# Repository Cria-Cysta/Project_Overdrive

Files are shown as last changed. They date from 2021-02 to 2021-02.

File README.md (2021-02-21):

# Project overdrive

Overdrive Model Ver. 21B20

>中文版介绍请点击[这里](https://shimo.im/docs/xqpTWwy3x8qtTTDj/)。

### What is it?

It's a game controller which designed for SDVX E-cloud, USC, KSM.

Compared with other controllers, it has a compromise size. When I designing this controller, I have tried to find a size to adapt to as many hand shapes as possible. And that it is.

### Features

It have bigger size to allow you could easily touch the BT-button. 3D-printed BT-buttons make the   finger contact area larger than standard keyboard key. Slightly inward moved position of FX-button relaxed your thumbs when you're playing.

### Materials

In order to make this controller, you'll need: 

1. Cover 3D-printed parts ×1
2. Middle bracket 3D-printed parts ×1
3. Lower lid 3D-printed parts ×1
4. BT-button 3D-printed parts ×4
5. EC11 rotary encoder ×2
6. PCB ×1 (thickness: 1.6mm)
7. Keyboard axis ×7
8. Satellite axis ×8
9. Pro micro development board ×1, With solder pins
10. Several GB M2×18 countersunk screw 
11. 20cm Micro USB male to female Type-C converter ×1.
12. Φ25mm knob ×2
13. 1u×1u DSA Keycap ×1
14. 1u×1.75u DSA Keycap ×2
15. Φ10mm mat ×4

In addition, you also need to prepare solder, flux, electric soldering iron and other tools used to solder the circuit board, as well as a small Phillips screwdriver. Because 3D-printed parts may have dimensional tolerances, prepare sandpaper as appropriate. 

### Guide

In production, stay tuned ;-)

Because it is designed to be easy to assemble, you can try to assemble it yourself.

### About design

Q: Why is the appearance very round, despite the use of 3D printing, there is no design of extra protrusions?
A: When playing SDVX E-cloud or other laser-shoot-type games, due to the variety of gameplay requirements, if you are not familiar with the chart or playing the difficult music chart, it may lead to violent operations that vary from person to person. The smooth appearance can maximize the protection of the user's hands when playing.

Q: Why are there chamfers near the buttons?
A: Since this controller is a miniaturized controller, the size standard part refers to a part that made for a mechanical keyboard. The specifications of the BT button 2U*2U are not guaranteed to fit everyone's hands. Therefore, in order to prevent the nails from reaching the gap and being caught, all buttons are designed with chamfers. 

Q: Why did the position of the FX button move inward?
A: The two FX buttons move inward for convenience. The design of the controller is for ease of use or to restore the feel of the arcade. These two design directions will inevitably have contradictions in some aspects. The inward movement of the FX button can reduce the accumulation of fatigue caused by long-term play under the design of the hand console, and it can also take care of players with relatively short finger lengths.

Q: Why is there no LED light like other miniaturized controllers?
A: Future versions consider adding this feature.

Q: Since the design is based on the size of the mechanical keyboard, why does the controller use non-standard BT keys?
A: The shaft of the existing 2U*2U keys on the market is not in the center. Whether it is adding a shaft body or filling the remaining slots with a satellite shaft, it will seriously affect the feel of the button and the force feedback. 

### Others

This work is licensed under a Creative Commons Attribution-NonCommercial-ShareAlike 4.0 International License.

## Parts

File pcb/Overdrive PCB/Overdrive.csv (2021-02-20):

ID | 位号 | 包 | 数量 | 名称 | 供应商和位号
1 | U1 | SparkfunPromicro | 1 | ProMicro
2 | START1 | MXOnly-1U-NoLED | 1 | KEYSW
3 | FX-R1,FX-L1 | MXOnly-1.75U-NoLED | 2 | KEYSW
4 | BT-D1,BT-C1,BT-B1,BT-A1 | MXOnly-2U-NoLED | 4 | KEYSW
5 | LASER-R1,LASER-L1 | RotaryEncoder_Alps_EC11E_Vertical_H20mm | 2 | EC11_without_switch

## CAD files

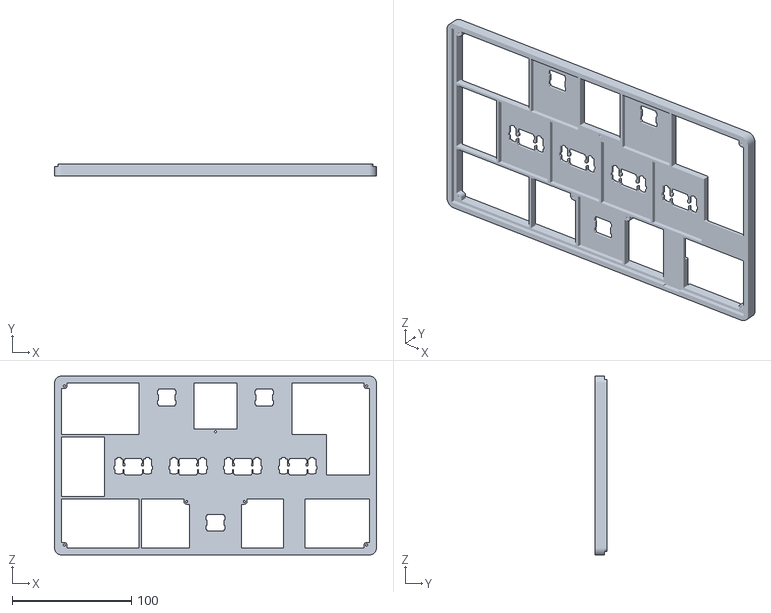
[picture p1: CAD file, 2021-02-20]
model/Middle_bracket.STL
270.0 x 10.0 x 150.0

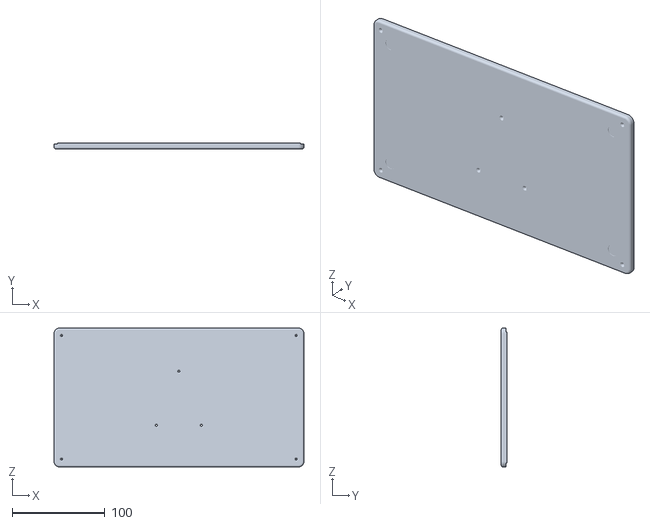
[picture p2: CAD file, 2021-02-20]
model/Lower_lid.STL
270.0 x 6.20 x 150.0

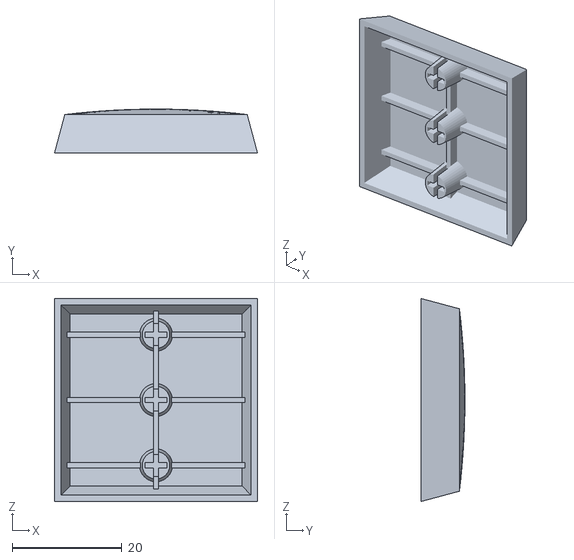
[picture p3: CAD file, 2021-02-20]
model/BT.STL
37.0 x 8.00 x 37.0

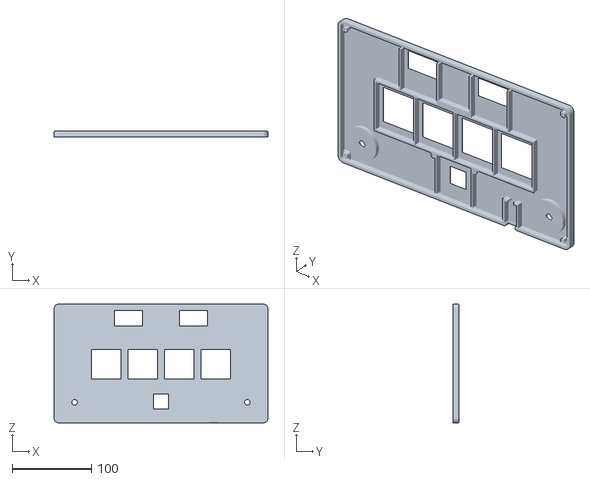
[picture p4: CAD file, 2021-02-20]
model/Cover.STL
270.0 x 8.00 x 150.0

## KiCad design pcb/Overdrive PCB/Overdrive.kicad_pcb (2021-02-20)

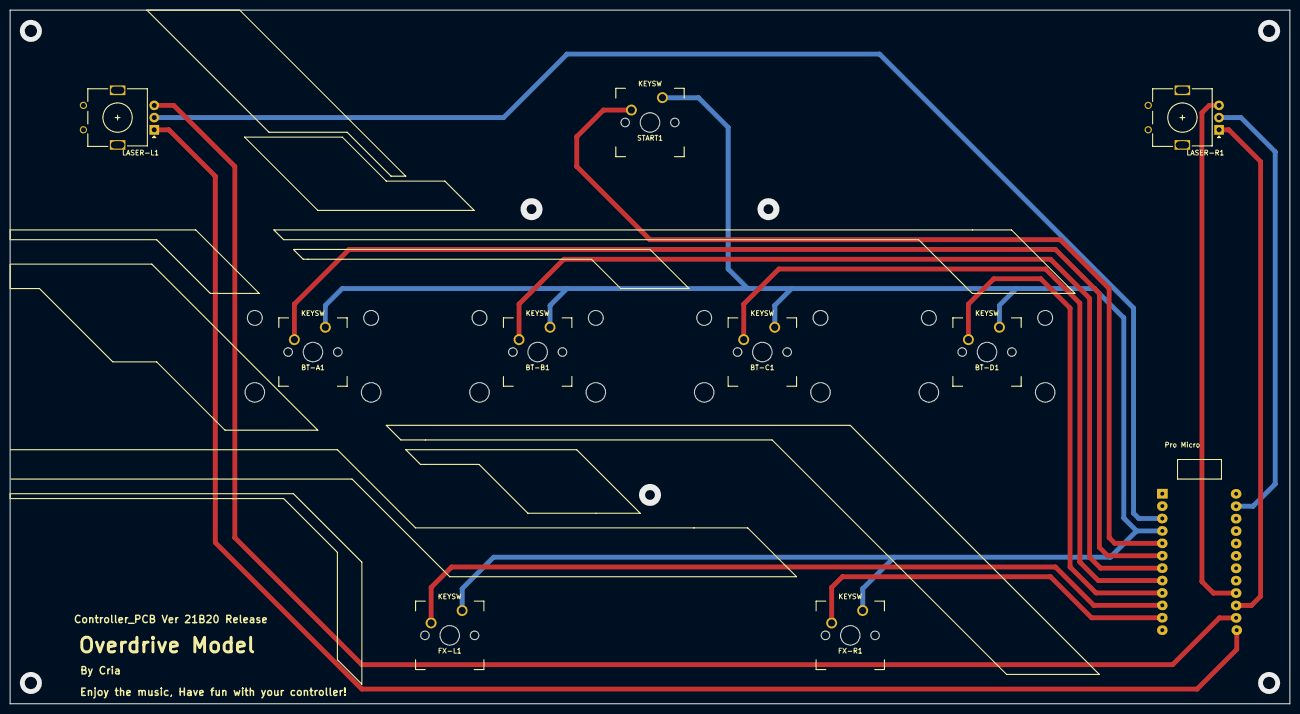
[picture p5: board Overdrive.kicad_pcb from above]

Board: 2 copper layers, 262.0 x 142.0 mm, 10 parts (0 on the bottom side), 14 nets.

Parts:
BT-A1: KEYSW; MXOnly-2U-NoLED
BT-B1: KEYSW; MXOnly-2U-NoLED
BT-C1: KEYSW; MXOnly-2U-NoLED
BT-D1: KEYSW; MXOnly-2U-NoLED
FX-L1: KEYSW; MXOnly-1.75U-NoLED
FX-R1: KEYSW; MXOnly-1.75U-NoLED
LASER-L1: EC11_without_switch; RotaryEncoder_Alps_EC11E_Vertical_H20mm
LASER-R1: EC11_without_switch; RotaryEncoder_Alps_EC11E_Vertical_H20mm
START1: KEYSW; MXOnly-1U-NoLED
U1: ProMicro; SparkfunPromicro

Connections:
unnamed: BT-A1.1, U1.3
unnamed: BT-A1.2, BT-B1.2, BT-C1.2, BT-D1.2, FX-L1.2, FX-R1.2, START1.2, U1.GND2
unnamed: BT-B1.1, U1.4
unnamed: BT-C1.1, U1.5
unnamed: BT-D1.1, U1.6
unnamed: FX-L1.1, U1.7
unnamed: FX-R1.1, U1.8
unnamed: LASER-L1.A, U1.10
unnamed: LASER-L1.B, U1.16
unnamed: LASER-L1.C, U1.GND1
unnamed: LASER-R1.A, U1.14
unnamed: LASER-R1.B, U1.15
unnamed: LASER-R1.C, U1.GND3
unnamed: START1.1, U1.2

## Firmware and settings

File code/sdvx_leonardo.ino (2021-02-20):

/*
* Modify by Cria_Cysta 
* By Daniel Tam (daniel@danieltam.net)
============ NOTES ============
The code is for Project Overdrive's hardwares Ver 21B20.
You will need to download the encoder library and use it in your project for this to work (ww.circuitsathome.com/mcu/reading-rotary-encoder-on-arduino)
===============================
*/

// buttons
#define BT_A 2
#define BT_B 3
#define BT_C 4
#define BT_D 5
#define FX_L 6
#define FX_R 7
#define BT_ST 8

// encoders
#include <Encoder.h>
Encoder enc1(10, 16);
Encoder enc2(15, 14);
float knob1 = 0;
float knob2 = 0;
float old_knob1 = 0;
float old_knob2 = 0;

void setup()
{ 
  // set pins to read, and output high
  // when the pins read low, we know that the buttons have went to ground (aka, pushed down)
  pinMode(BT_A, INPUT);
  pinMode(BT_B, INPUT);
  pinMode(BT_C, INPUT);
  pinMode(BT_D, INPUT);
  pinMode(FX_L, INPUT);
  pinMode(FX_R, INPUT);
  pinMode(BT_ST, INPUT);
  
  digitalWrite(BT_A, HIGH);
  digitalWrite(BT_B, HIGH);
  digitalWrite(BT_C, HIGH);
  digitalWrite(BT_D, HIGH);
  digitalWrite(FX_L, HIGH);
  digitalWrite(FX_R, HIGH);
  digitalWrite(BT_ST, HIGH);
  
  Mouse.begin();
  Keyboard.begin();
}

void loop()
{
  // read encoders
  knob1 =  (float)(enc1.read());
  knob2 = (float)enc2.read();
  
  if(knob1 != old_knob1)
  {
    // if there's a difference in encoder movement from last pass, move the mouse
    if(knob1 < old_knob1)
    {
      Mouse.move(0, -10);
    }
    else
    {
      Mouse.move(0, 10);
    }
    
	// we count the difference in the encoders, but we must not go over arduino's int limit
    if(knob1 < -255)
    {
      enc1.write(0);
      old_knob1 = 0;
    }
    else if (knob1 > 255)
    {
      enc1.write(0);
      old_knob1 = 0;
    }
    else
    {
      old_knob1 = knob1;
    }
  }
  
  if(knob2 != old_knob2)
  {
    if(knob2 > old_knob2)
    {
      Mouse.move(-10, 0);
    }
    else
    {
      Mouse.move(10, 0);
    }
    
    if(knob2 < -255)
    {
      enc2.write(0);
      old_knob2 = 0;
    }
    else if(knob2 > 255)
    {
      enc2.write(0);
      old_knob2 = 0;
    }
    else
    {
      old_knob2 = knob2;
    }
  }
  
  // read the buttons for low, if it's low, output a keyboard press  
  if(digitalRead(BT_A) == LOW)
  {
    Keyboard.press('a');
  }
  else
  {
    Keyboard.release('a');
  }
  
  if(digitalRead(BT_B) == LOW)
  {
    Keyboard.press('b');
  }
  else
  {
    Keyboard.release('b');
  }
  
  if(digitalRead(BT_C) == LOW)
  {
    Keyboard.press('c');
  }
  else
  {
    Keyboard.release('c');
  }
  
  if(digitalRead(BT_D) == LOW)
  {
    Keyboard.press('d');
  }
  else
  {
    Keyboard.release('d');
  }
  
  if(digitalRead(FX_L) == LOW)
  {
    Keyboard.press('z');
  }
  else
  {
    Keyboard.release('z');
  }
  
  if(digitalRead(FX_R) == LOW)
  {
    Keyboard.press('x');
  }
  else
  {
    Keyboard.release('x');
  }
  
  if(digitalRead(BT_ST) == LOW)
  {
    Keyboard.press('n');
  }
  else
  {
    Keyboard.release('n');
  }
}
